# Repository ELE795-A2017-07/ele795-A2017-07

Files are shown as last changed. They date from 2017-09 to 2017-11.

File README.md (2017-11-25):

This is the project as handed out by the previous team. It used a Arduino node rather than a Raspberry Pi one.

# This is the BELIOT project
This is an Internet Of Things project.
This project contains an Arduino Nano which is the core microcontroller of module.
The module contains an RF circuit (inAir9B) with LoRaWAN technology. This node sends
data to a Raspberry Pi via RF and the Raspberry Pi posts its data to a Webserver via a Ruby script.
Webserver (Ruby on Rails app) can be reached at beliotv3.herokuapp.com. Data is stored into InfluxDB and can be visualized with Grafana.

This unit monitors:
- soil humidity and temperature
- air humidity and temperature
- Ozone concentration
- Dust concentration
- GPS
- Battery Life

Here is a picture of the Arduino node:
beliot_pic

Here is the circuitry inside the Stevenson Cage:
the_whole_thing

Here is the Raspberry Pi Gateway to receive/send data:
raspgithub

Here is a picture of a successful transmission from the Arduino node to the Raspberry Pi (seen on rasp console):
successfull_com

Here is the landing page of the website:


Here is some data plotted using Grafana:
some_data

The PCBs and electronics circuits were made using the KiCad software.

A User Manual (in French) is to be found on PDF.

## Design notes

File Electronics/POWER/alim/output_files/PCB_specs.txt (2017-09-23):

PCB specs
-2 layers external (Top, bottom)
-FR4 (130TG)
-Copper weight external: 1 oz/ft2 
-Core thickness:0.063"
-Legend color: white
-Mask color: green
-Finish: Lead-free HASL

https://www.eeweb.com/electronics-quiz/calculate-the-capacitance-of-pcb-planes
PCB cap: 1pF
-Solder mask min: 0.005"
-Traces et clearance min: 0.005"

http://circuitcalculator.com/wordpress/2006/01/31/pcb-trace-width-calculator/

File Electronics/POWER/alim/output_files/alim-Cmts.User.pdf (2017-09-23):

General specifications:
-2 layers external (Top, bottom) -Material: FR4
-Copper weight external: 1 oz/ft^2 -Silkscreen color: white
-Solder mask color: green
-Finish: Lead-free HASL
-Core thickness: 0.063"

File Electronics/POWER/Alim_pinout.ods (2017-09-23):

Signal | Broches | Description
Bat+ | 1 | Tension aux bornes de la batterie
uCV | 2 | Tension d’alimentation 5V fournie au microcontrôleur
5V | 3 | Tension d’alimentation 5V fournie aux senseurs
3.3V | 4 | Tension d’alimentation 3.3V fournie aux senseurs
3V | 5 | Tension d’alimentation 3V fournie aux senseurs
GND | 6 | Mise à la terre du circuit d’alimentation
EnuC ou EuC | 7 | Broche d’activation de l’alimentation du microcontrôleur. Haut niveau = actif, Bas niveau = inactif
EN5V ou E5V | 8 | Broche d’activation de l’alimentation des capteurs 5V. Haut niveau = actif, Bas niveau = inactif
EN3.3V ou E33V | 9 | Broche d’activation de l’alimentation des capteurs 3.3V. Haut niveau = actif, Bas niveau = inactif
EN3V ou E3V | 10 | Broche d’activation de l’alimentation des capteurs 3V. Haut niveau = actif, Bas niveau = inactif
SolCtrl | 11 | Permet d’asservir le chargeur avec des niveaux logiques, si les connecteurs sont connecté en mode nMOS. Bas niveau = panneau solaire connecté au chargeur. Haut niveau = panneau solaire déconnecté du chargeur
Status | 12 | Donne le status de charge de la batterie. Niveau haut = charge complétée. Bas niveau = batterie en chargement. Haute impédance = hors service ou pas de batterie.

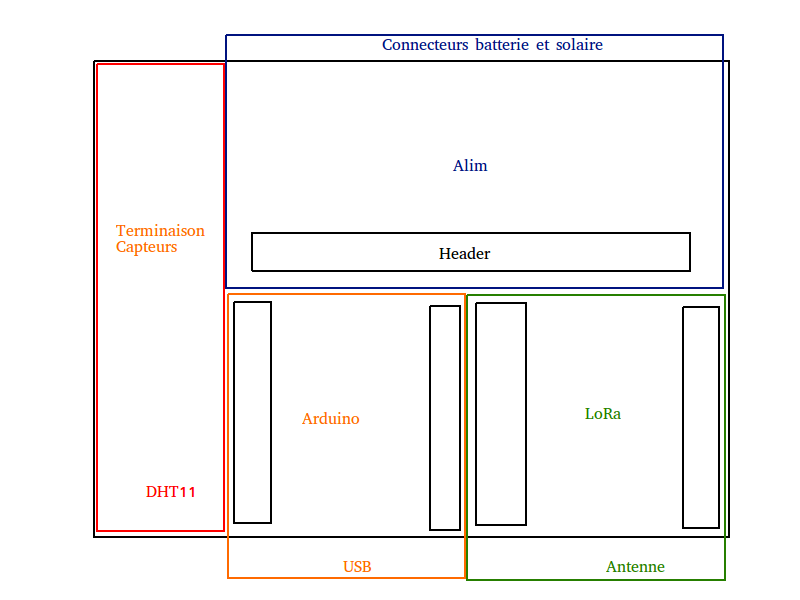
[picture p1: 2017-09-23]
Electronics/SENSOR_UNIT/Disposition_physique.png

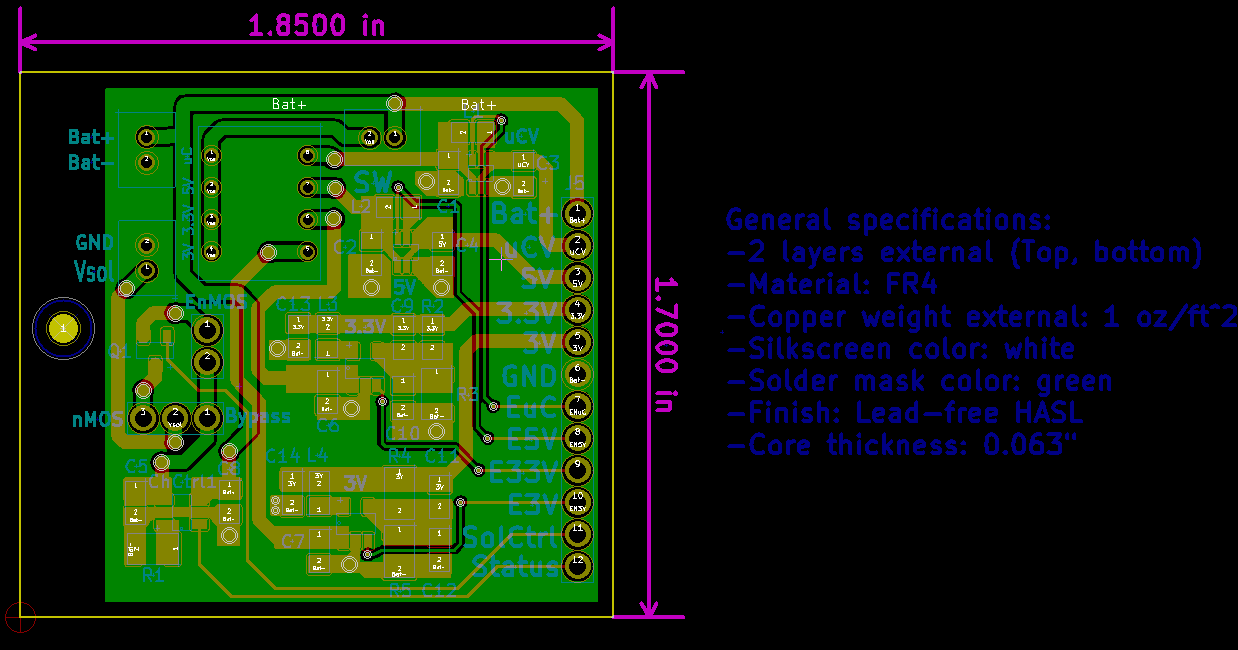
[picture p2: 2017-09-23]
Electronics/POWER/TopNBottom.png

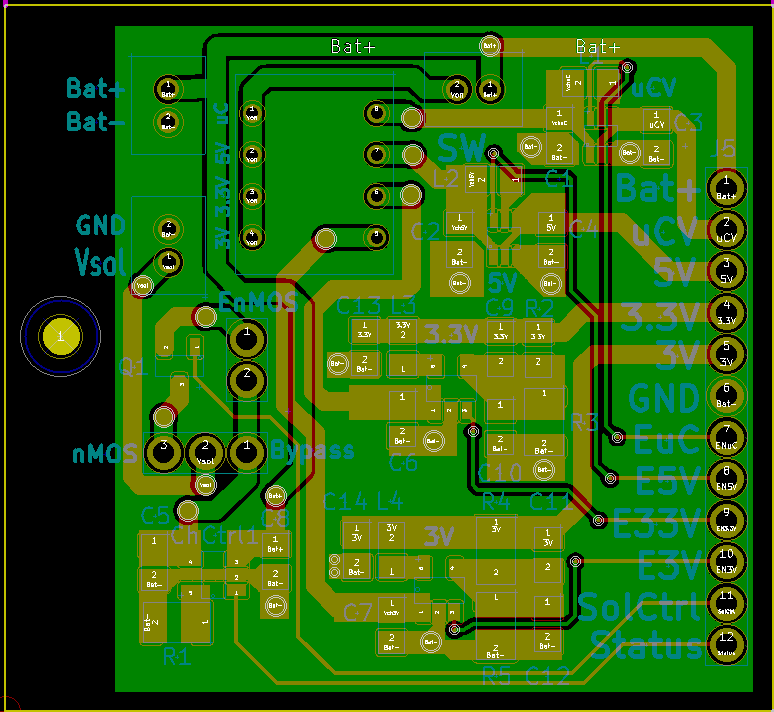
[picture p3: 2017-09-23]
Electronics/POWER/alim/pcb_power.png

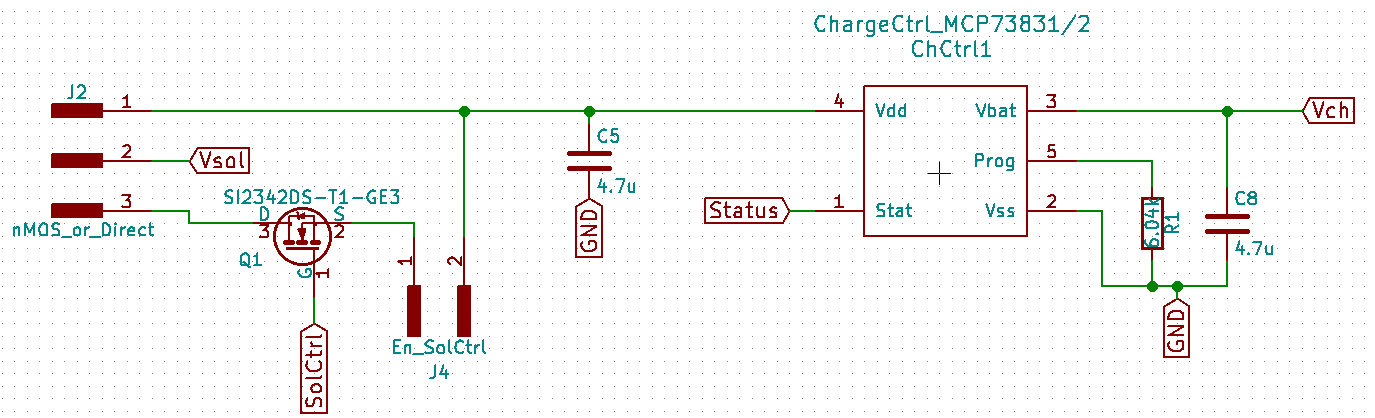
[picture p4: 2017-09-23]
Electronics/POWER/reg_chargeur.png

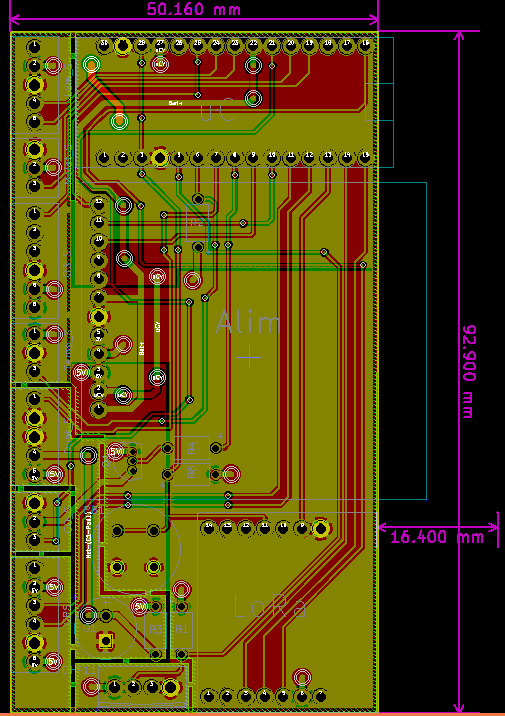
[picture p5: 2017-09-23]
Electronics/SENSOR_UNIT/PCB_final_taille.png

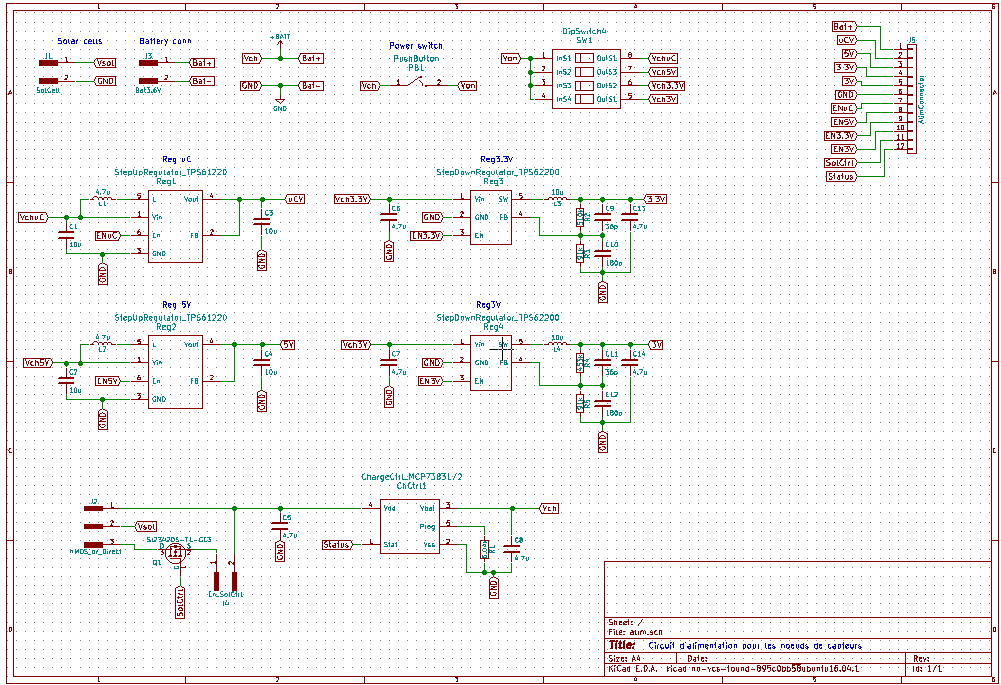
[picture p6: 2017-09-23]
Electronics/POWER/Circuit_power.png

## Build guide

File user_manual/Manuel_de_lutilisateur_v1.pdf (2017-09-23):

# Manuel de l’utilisateur v1

Noeud + Passerelle LoRa, Projet Beliot

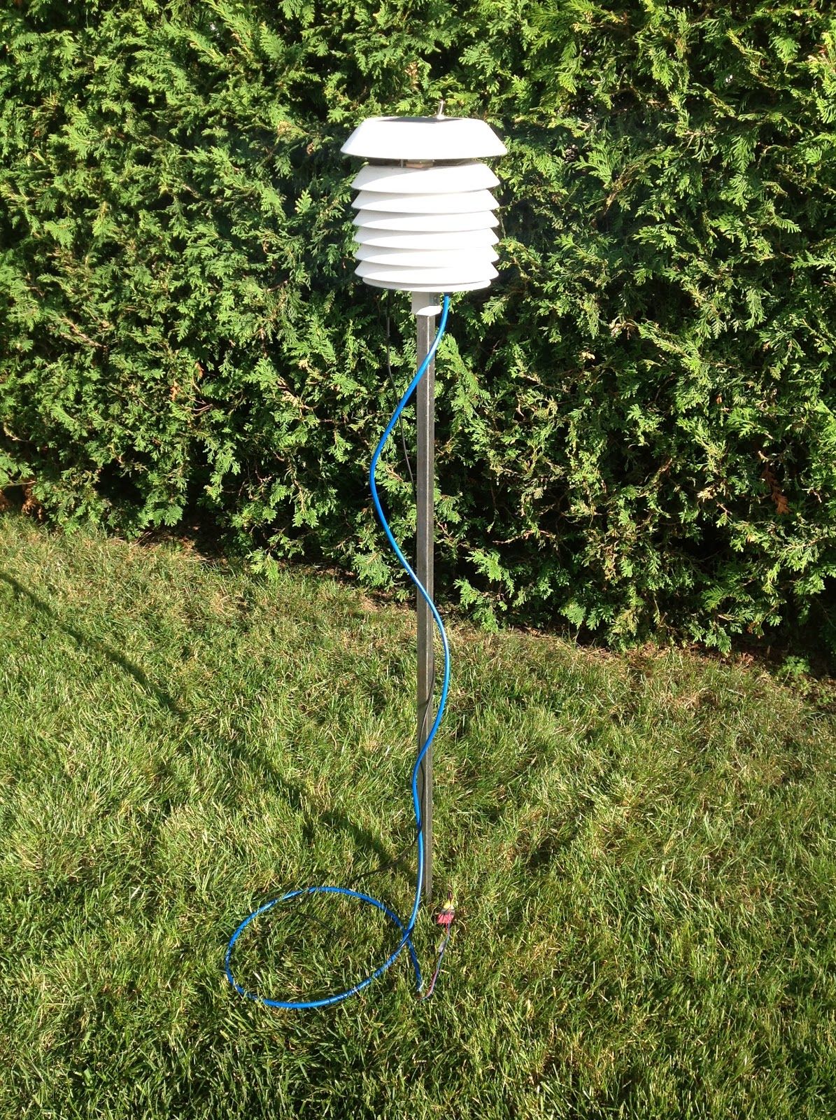
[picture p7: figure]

Par
Vincent Gosselin

Fait le 8 Août 2017

# Table des matières

Installation de la passerelle | p.3-5
Installation du noeud | p.5-6
La Plateforme Web | p.7
Où trouver le travail réalisé | p.7
Considérations importantes | p.8

# Installation de la passerelle

1. Brancher le Raspberry Pi dans un routeur à l’aide d’un cable Ethernet.
2. Brancher l’alimentation du Raspberry Pi.
3. Mettre le Raspberry PI a “ON’’ (alimenter)
4. Découvrir et noter le IP local du Raspberry PI à l’aide de la page web du routeur. Chez moi, le routeur à l’adresse ‘’http//home/”.
5. À l’aide de la console tapez :
‘’ssh pi@XXX.XXX.XXX.XXX’’
où XXX.XXX.XXX.XXX correspond au IP découvert à l’étape 4.
6. Le mot de passe est :
‘’raspberry’’
7. Une fois entrer dans le raspberry pi, tapez la commande : ‘’tmux ls’’.
La commande va retourner un message d’erreur si il n’y a pas de session tmux déjà lancé:

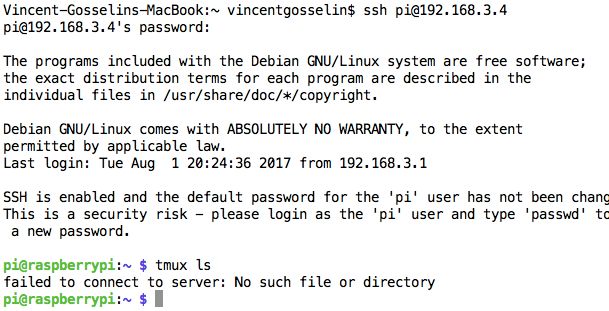
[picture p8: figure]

Si il y avait un serveur tmux de disponible, il suffit de tapper “tmux attach’’ pour se connecter à la session tmux.

8. Tapez la commande ‘’tmux’’ pour démarrer une nouvelle session tmux.
Une fois la session tmux lancé, une barre verte apparait en bas d’écran.

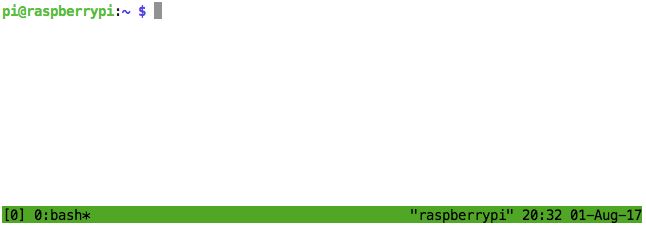
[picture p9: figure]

9. Entrer la commande ‘’cd /home/pi/Desktop/LowCostLoRaGw/lora_gateway’’ pour accéder au répertoire de la passerelle LoRa.

10. Taper ‘’ls’’ pour voir le contenu du dossier.
À titre d’information :
- Le script STARTGATEWAY.sh sert à activer la passerelle.
- Le fichier lora_gateway.cpp sert à la configuration de la bande de fréquence du module LoRa. En Amérique, il s’agit de la bande 915 MHz. En Europe, il s’agit de la bande de 868 MHz. Après chaque modification de lora_gateway.cpp, il faut recompiler avec la commande ‘’make lora_gateway_pi2’’. Le raspberry pi a déjà été configuré en 868MHz.
- Le fichier post_to_influxdb_v3.rb sert à envoyer les données reçues de la passerelle vers la plateforme Web. Ce fichier a été placé dans clouds.json pour être appellé via le script post_processing_gw.py

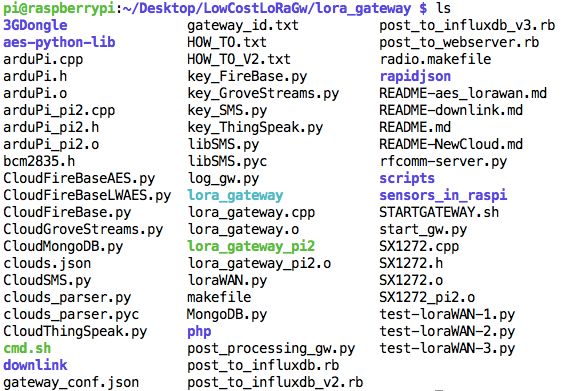
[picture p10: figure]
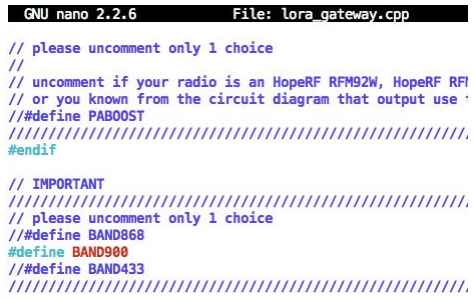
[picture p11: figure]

11. Taper ‘’bash STARTGATEWAY.sh’’ pour activer la passerelle. L’écran devrait alors avoir l’allure suivante :

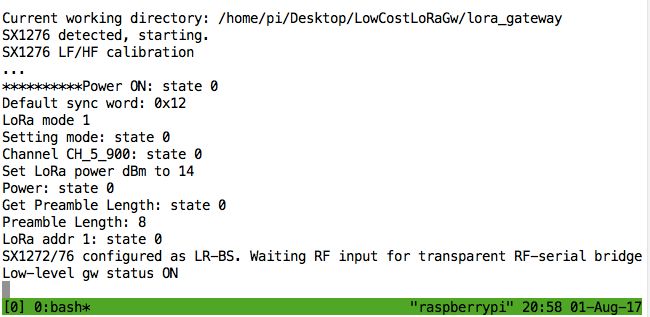
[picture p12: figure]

12. Enfoncer (CTRL+B), Relacher et appuyer sur D pour se déttacher de la session tmux.

13. Taper ‘’exit’’ pour se déconnecter du raspberry pi.

La passerelle est maintenant configuré.

# Installation de noeud

1. Planter la barre dans le sol a l’aide d’un maillet.
2. Installer la tête du prototype sur la barre de fer et visser la tête sur la barre de fer.

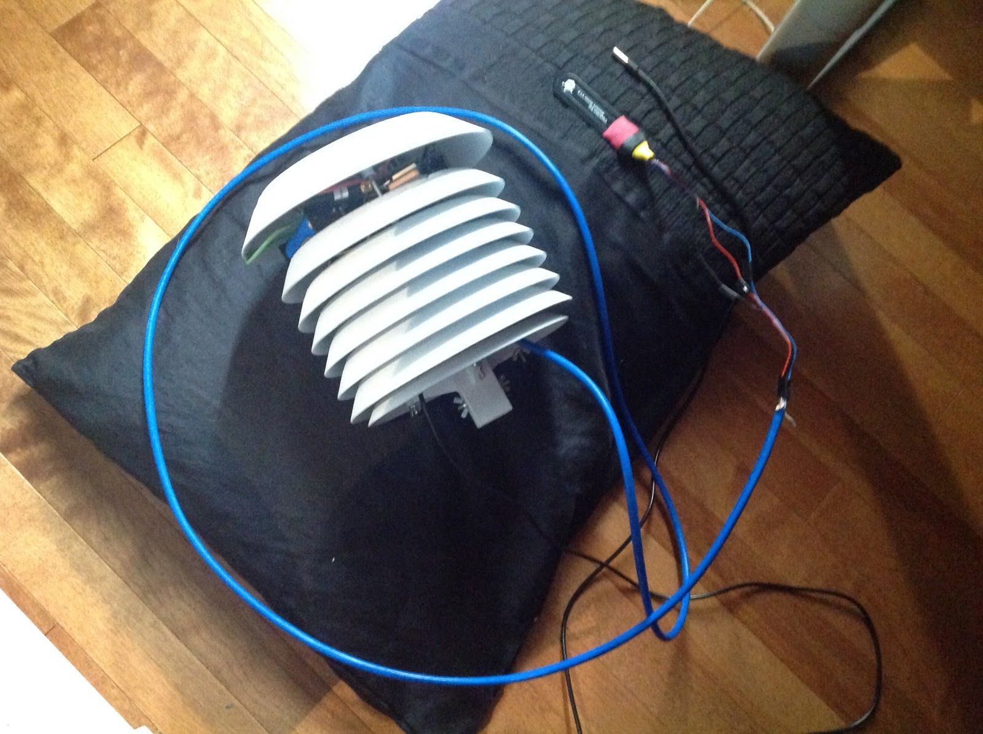
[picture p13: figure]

3. Activer la SWITCH à ON sur la tête du prototype pour mettre le noeud en mode actif.

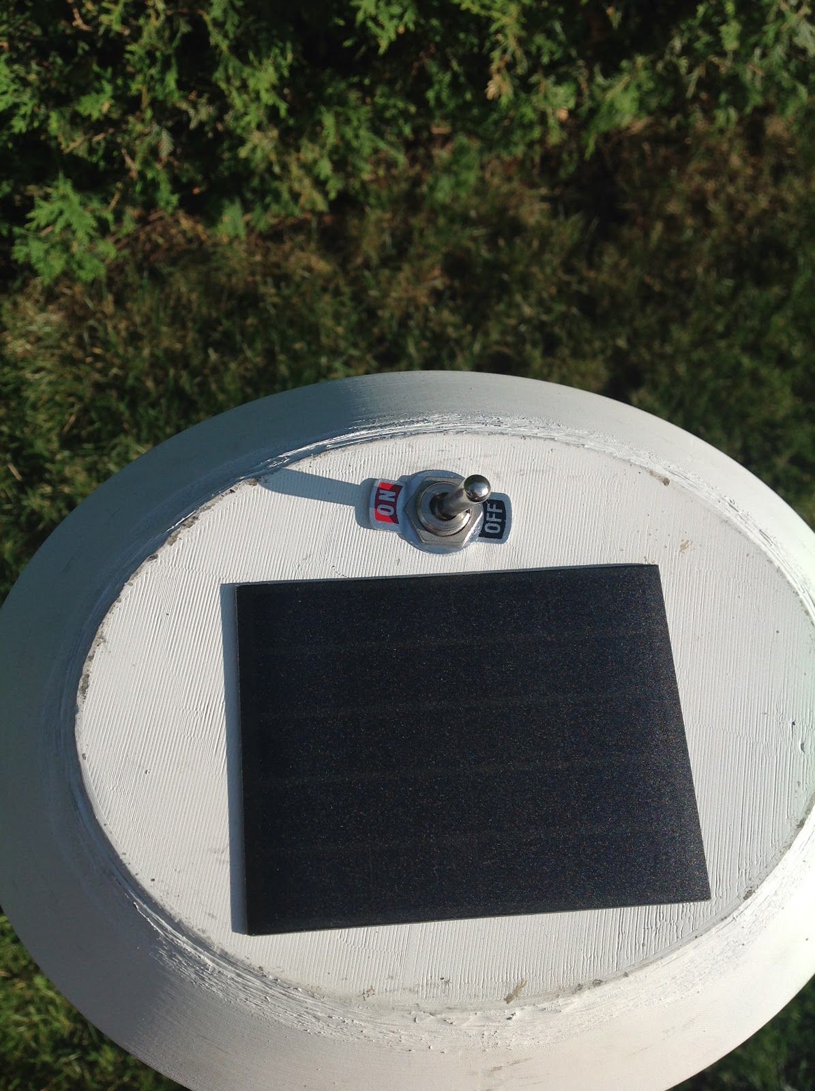
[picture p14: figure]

4. Après 40 secondes, un message sera reçu sur le rasp dans la session tmux pour indiquer une communication réussi.

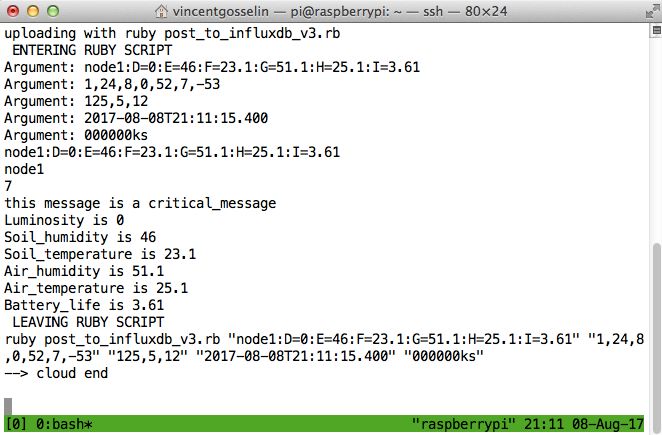
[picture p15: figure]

6. Planter dans le sol la sonde de température et la sonde d’humiditié.
7. En cas, d’échec de cette réception de donnée, Switch -> OFF, Switch -> ON, devrait réussir la communication. Parfois (rarement), il y a une erreur LoRa pendant la première transmission. Donc, éteindre et ré-allumer le prototype devrait faire.
8. Noter qu’il serait important d’avoir un recouvrement de la tête sur la partie supérieure afin de protéger la partie électronique du contact de l’eau.
9. Pour programmer le arduino attaché au prototype, il est très important de mettre la SWITCH à OFF avant de connecter le port USB.

# La plateforme Web

1. La plateforme Web est accessible à l’adresse beliotv3.herokuapp.com
2. Pour avoir les prévisions locales, Cliquer sur l’image de la météo.
3. Pour l’historique du noeud, Cliquer sur l’image de Grafana.
4. Sur Grafana, Usager : ‘’client’’ Mot de passe : ‘’vignesbordeaux’’
5. Sélectionner le Dashboard ‘’vignes_bordeaux_v1’’

Pour l’info, le site web est contenu sur la plateforme Heroku et est codé en Ruby. Le code du site web est disponible sur Github : https://github.com/vincentgosselin1/beliotv3 . La base de données Influxdb + Grafana sont hébergé sur la plateforme de Amazon Web Services.

Notez que la gratuité de la plateforme Web sur Amazon Web Services prend fin Mai 2018, prière de communiqué vincentgosselin1@gmail.com avant la date d’échéance.

# Où trouver le travail réalisé

1. La totalité du travail se trouve à l’adresse : https://github.com/vincentgosselin1/Arduino_node
2. Le code principale qui doit être flashé dans le arduino nano se trouvre dans le dossier Main et se nomme ‘’main.cpp”. Afin de compiler le code dans le arduino, il est important de copier/coller la totalité du fichier main.cpp dans un fichier .ino pour flasher le arduino. En plus, il faut copier le contenu du dossier ‘’libraries’’ dans le répertoire des libraries Arduino. Sur mon Macbook, la location de ce dossier se trouve dans ‘’/Users/vincentgosselin/Documents/Arduino/libraries’’.
3. Les projets Kicad pour les circuits électriques ainsi que les pcbs sont inclus dans le Github dans la section Electronics.

# Considération importantes

1. Le module consomme plus que prévue, un erreur au niveau de la conception électrique sur un régulateur force la consommation à 150mA en mode actif et à 60mA en mode économie d’énergie. La faute est à cause de la ligne 5V qui ne va pas à 0V quand le régulateur ‘’shut-off’’. En enlevant le GPS + Détecteur de poussière, la consommation passe à 40mA en mode actif et 10mA en mode économie d’énergie. Pour une raison qu’on ignore encore, le mode économie d’énergie observer sur plaque d’essais, ne descend pas jusqu’à 0.25mA. Ceci est à investiguer.
2. Il faut recouvrir la partie suppérieure de la tête du prototype pour le rendre imperméable à l’eau (la partie inférieur l’est). Du simple “Duck tape’’ fait l’affaire.
3. Un optimisation de code a été fait mais elle s’est avéré inéfficace puisque le programme atteignait 98% de mémoire statique et 80% mémoire dynamique avec l’inclusion du capteur de luminosité. La communication LoRa ne fonctionnait pas et un message de ‘’warning’’ sur Arduino apparaissait. Alors, c’est pour cette raison que le capteur de luminosité ne fait pas partie du prototype. Le code est stable maintenant.

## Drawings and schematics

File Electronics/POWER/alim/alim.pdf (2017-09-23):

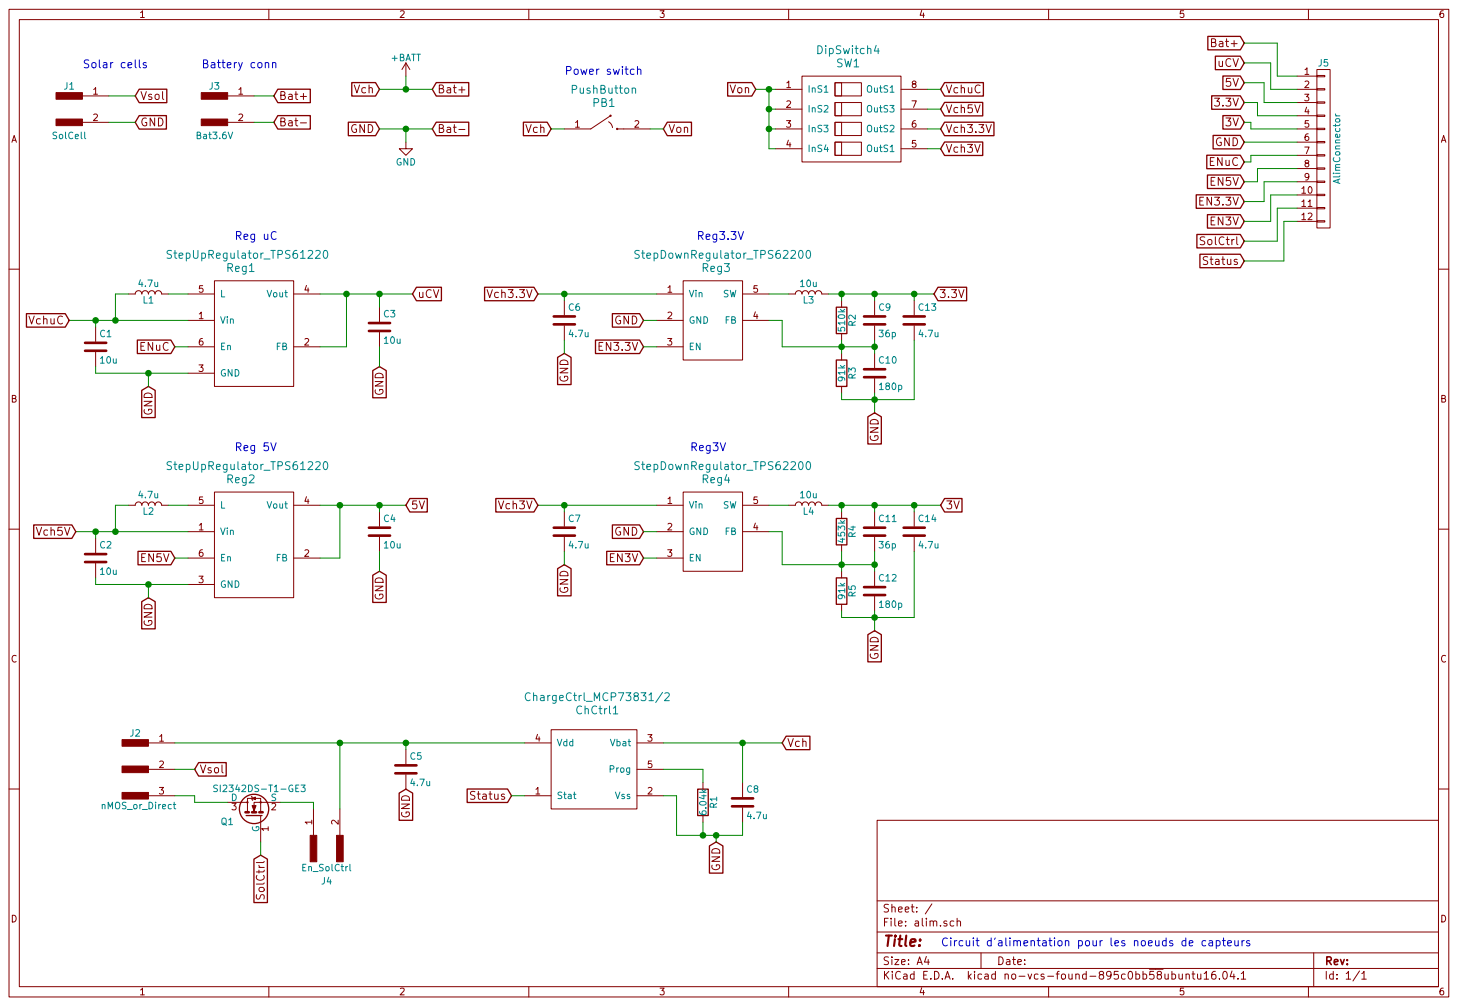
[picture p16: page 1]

Circuit d'alimentation pour les noeuds de capteurs

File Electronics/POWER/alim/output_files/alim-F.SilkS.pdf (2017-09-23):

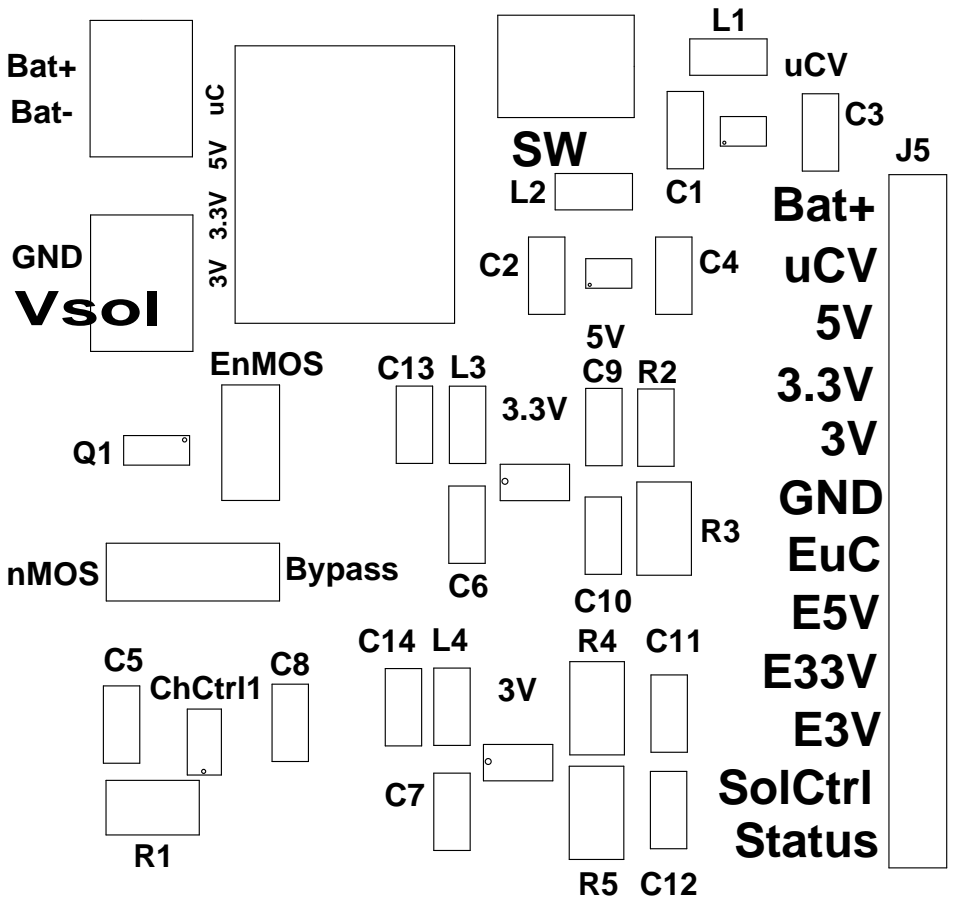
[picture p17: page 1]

3V 3.3V 5V uC EnMOS Bat- nMOS Bypass Bat+ Vsol SW

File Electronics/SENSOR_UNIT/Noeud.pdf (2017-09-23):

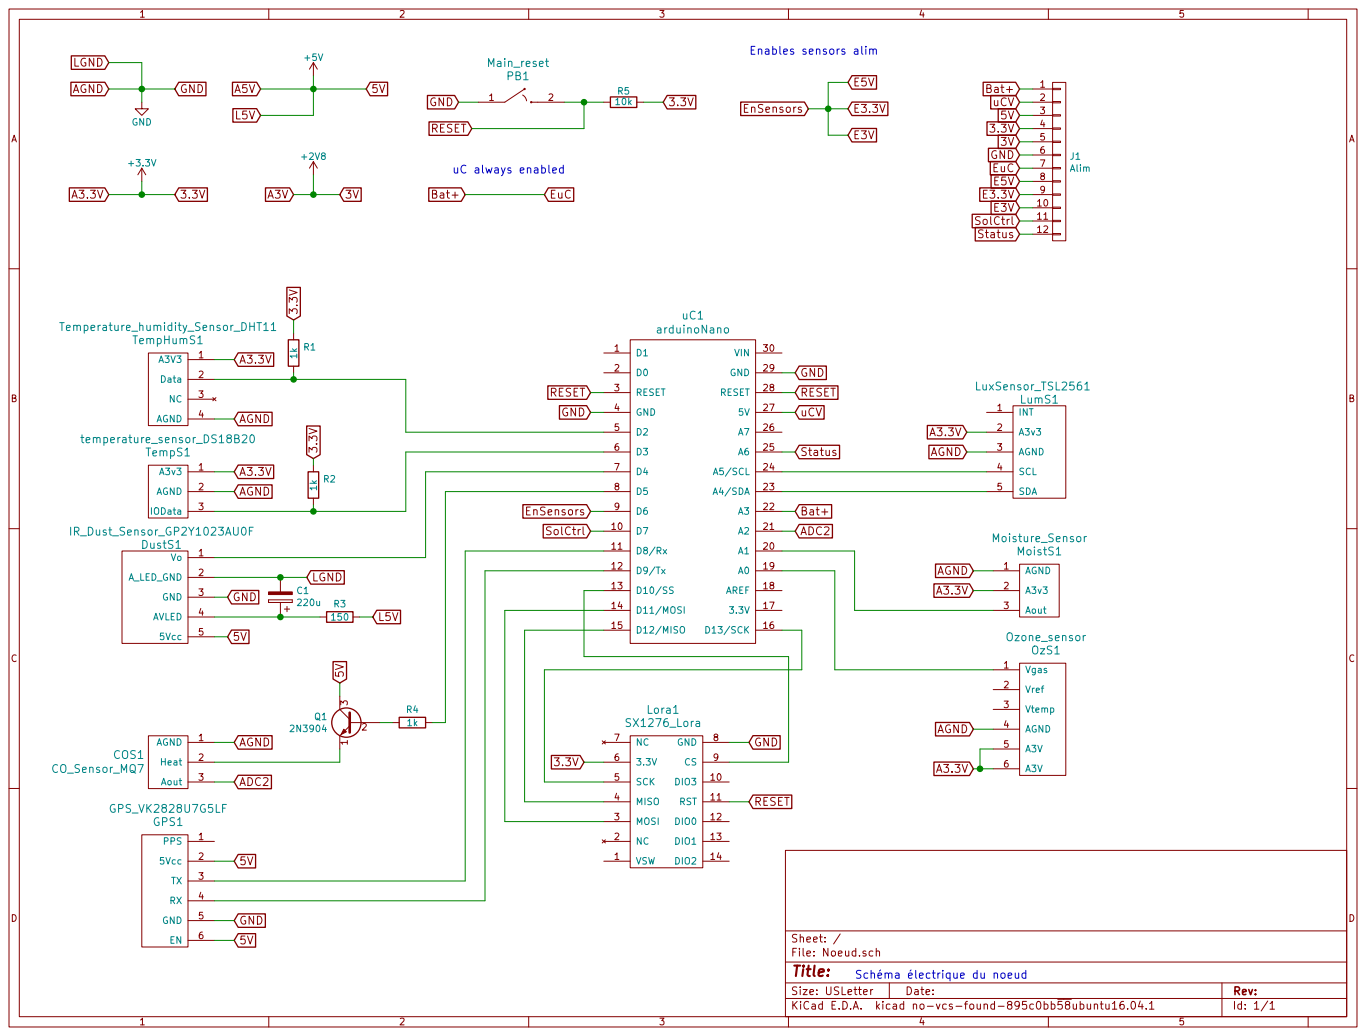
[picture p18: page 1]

Id: 1/1 Title: File: Noeud.sch Sheet: /

Schéma électrique du noeud

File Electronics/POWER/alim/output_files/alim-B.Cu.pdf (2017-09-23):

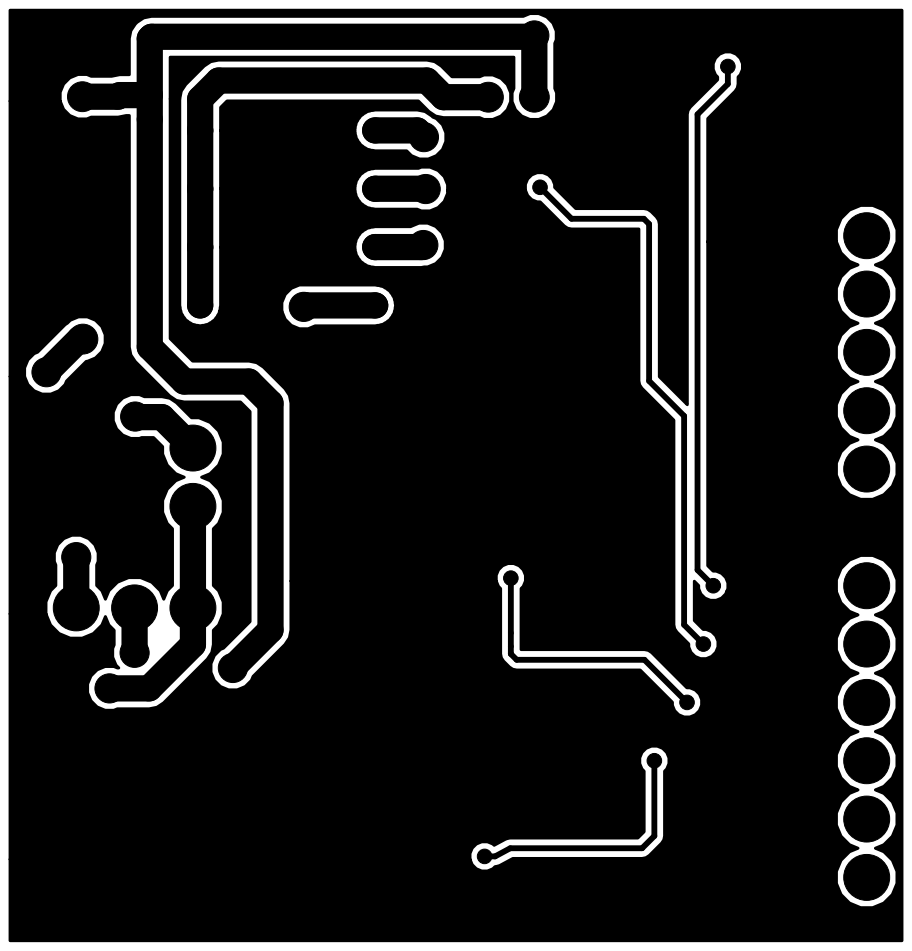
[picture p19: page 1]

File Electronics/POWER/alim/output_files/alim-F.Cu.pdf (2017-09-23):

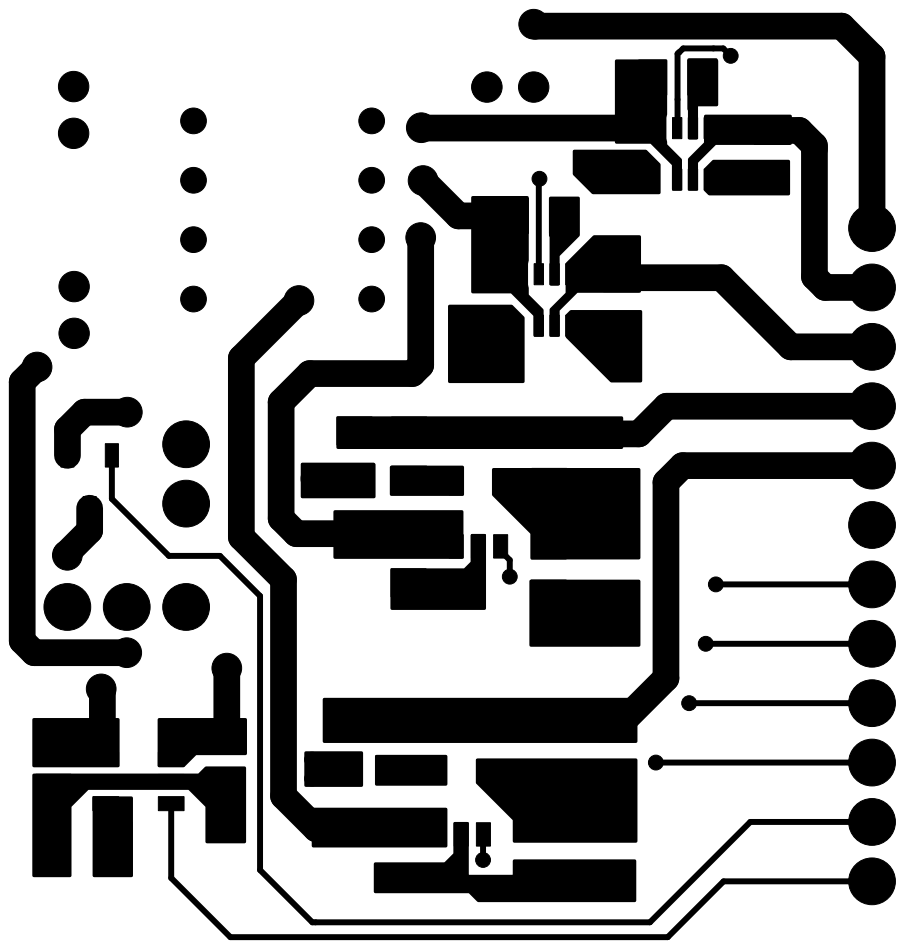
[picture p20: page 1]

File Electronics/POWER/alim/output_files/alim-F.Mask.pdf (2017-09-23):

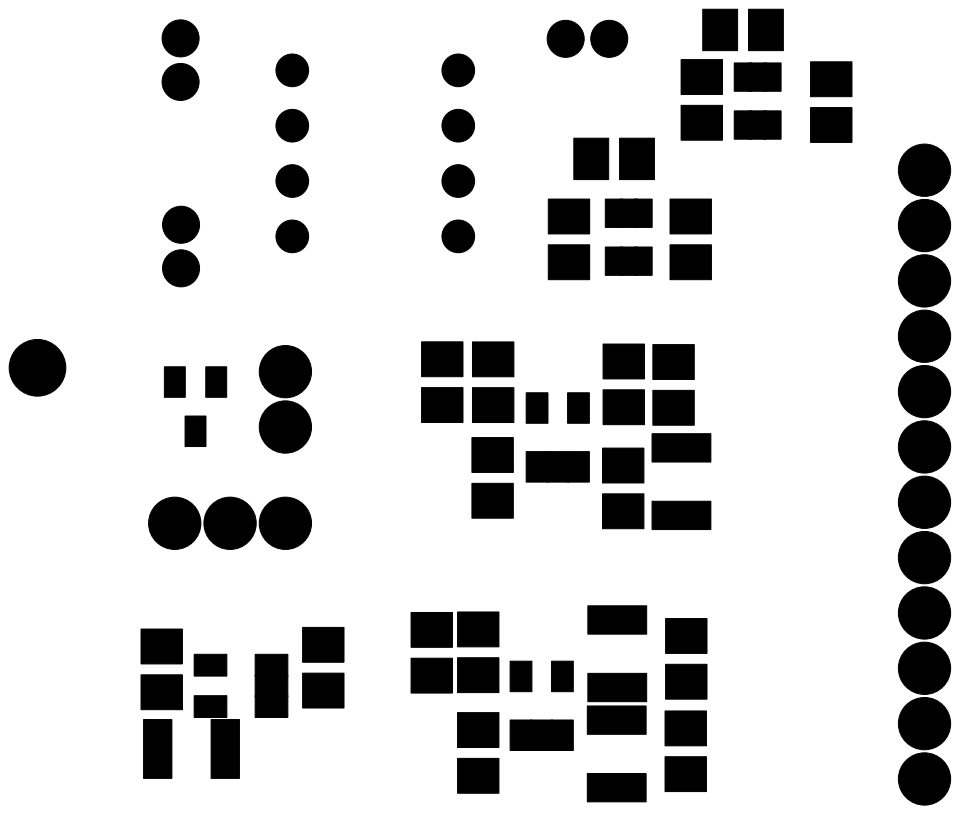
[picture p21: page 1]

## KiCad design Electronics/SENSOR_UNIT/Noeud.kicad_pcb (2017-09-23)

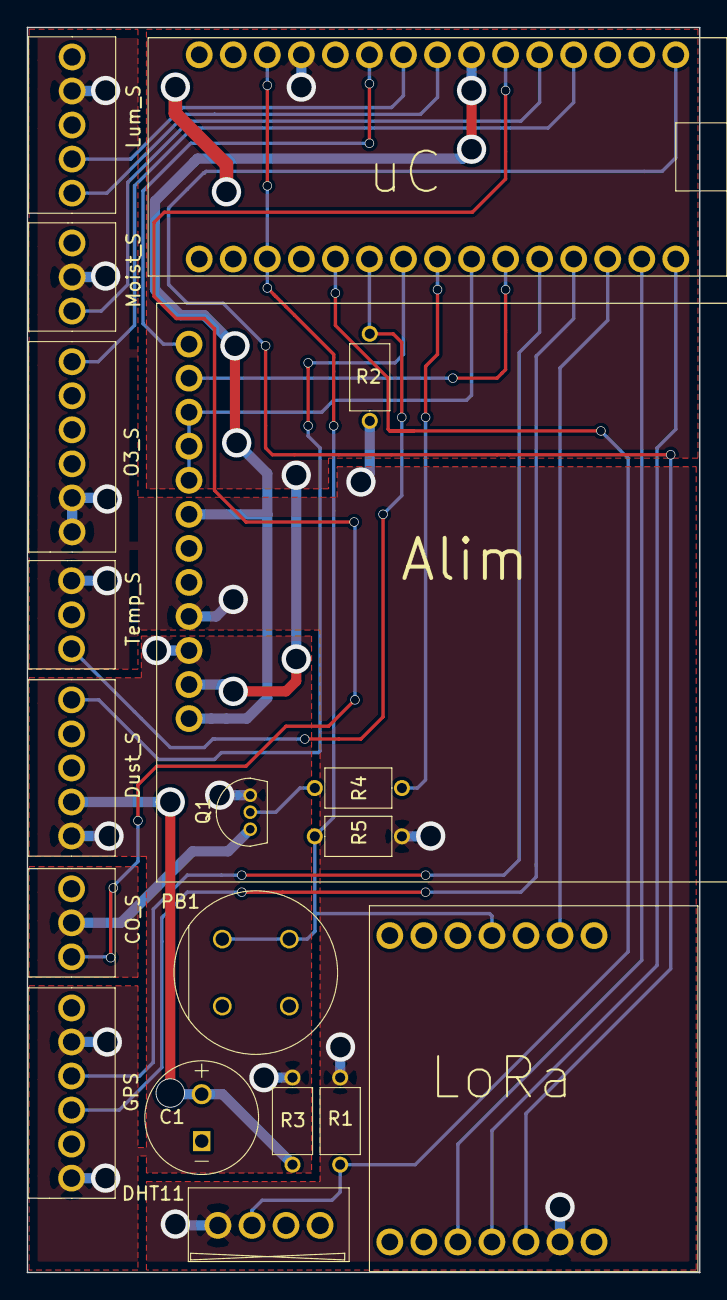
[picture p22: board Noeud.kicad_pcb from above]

Board: 2 copper layers, 50.2 x 92.9 mm, 19 parts (0 on the bottom side), 27 nets.

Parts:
C1: 220u; Axial_cap_220u
CO_S: CO_Sensor_MQ7; Block_terminal_X3
DHT11: Temperature_humidity_Sensor_DHT11; DHT11
Dust_S: IR_Dust_Sensor_GP2Y1023AU0F; Block_terminal_X5
GPS: GPS_VK2828U7G5LF; Block_terminal_X6
J1: Alim; Header_X12_0p1_power
LoRa: SX1276_Lora; SX1276_LoRa
Lum_S: LuxSensor_TSL2561; Block_terminal_X5
Moist_S: Moisture_Sensor; Block_terminal_X3
O3_S: Ozone_sensor; Block_terminal_X6
PB1: Main_reset; PushButton
Q1: 2N3904; Transistor_TO-92
R1, R2, R4: 1k; Axial_resistor_0p25W
R3: 150; Axial_resistor_0p25W
R5: 10k; Axial_resistor_0p25W
Temp_S: temperature_sensor_DS18B20; Block_terminal_X3
uC: arduinoNano; ArduinoNano

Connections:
3.3V: DHT11.1, J1.4, LoRa.6, Lum_S.2, Moist_S.2, O3_S.5, O3_S.6, R1.1, R2.1, R5.2, Temp_S.1
5V: Dust_S.5, GPS.2, GPS.6, J1.3, Q1.3, R3.1
ADC2: CO_S.3, uC.21
AGND: C1.2, CO_S.1, DHT11.4, Dust_S.2, Dust_S.3, GPS.5, J1.6, LoRa.8, Lum_S.3, Moist_S.1, O3_S.4, PB1.1, Temp_S.2, uC.4, uC.29
Bat+: J1.1, J1.7, uC.22
E3.3V: J1.8, J1.9, J1.10, uC.9
unnamed: C1.1, Dust_S.4, R3.2
unnamed: CO_S.2, Q1.1
unnamed: Dust_S.1, uC.7
unnamed: GPS.3, uC.11
unnamed: GPS.4, uC.12
unnamed: LoRa.3, uC.14
unnamed: LoRa.4, uC.15
unnamed: LoRa.5, uC.16
unnamed: LoRa.9, uC.13
unnamed: Lum_S.4, uC.24
unnamed: Lum_S.5, uC.23
unnamed: Moist_S.3, uC.20
unnamed: O3_S.1, uC.19
unnamed: Q1.2, R4.2
unnamed: DHT11.2, R1.2, uC.5
unnamed: R2.2, Temp_S.3, uC.6
unnamed: R4.1, uC.8
RESET: LoRa.11, PB1.2, R5.1, uC.3, uC.28
SolCtrl: J1.11, uC.10
Status: J1.12, uC.25
uCV: J1.2, uC.27

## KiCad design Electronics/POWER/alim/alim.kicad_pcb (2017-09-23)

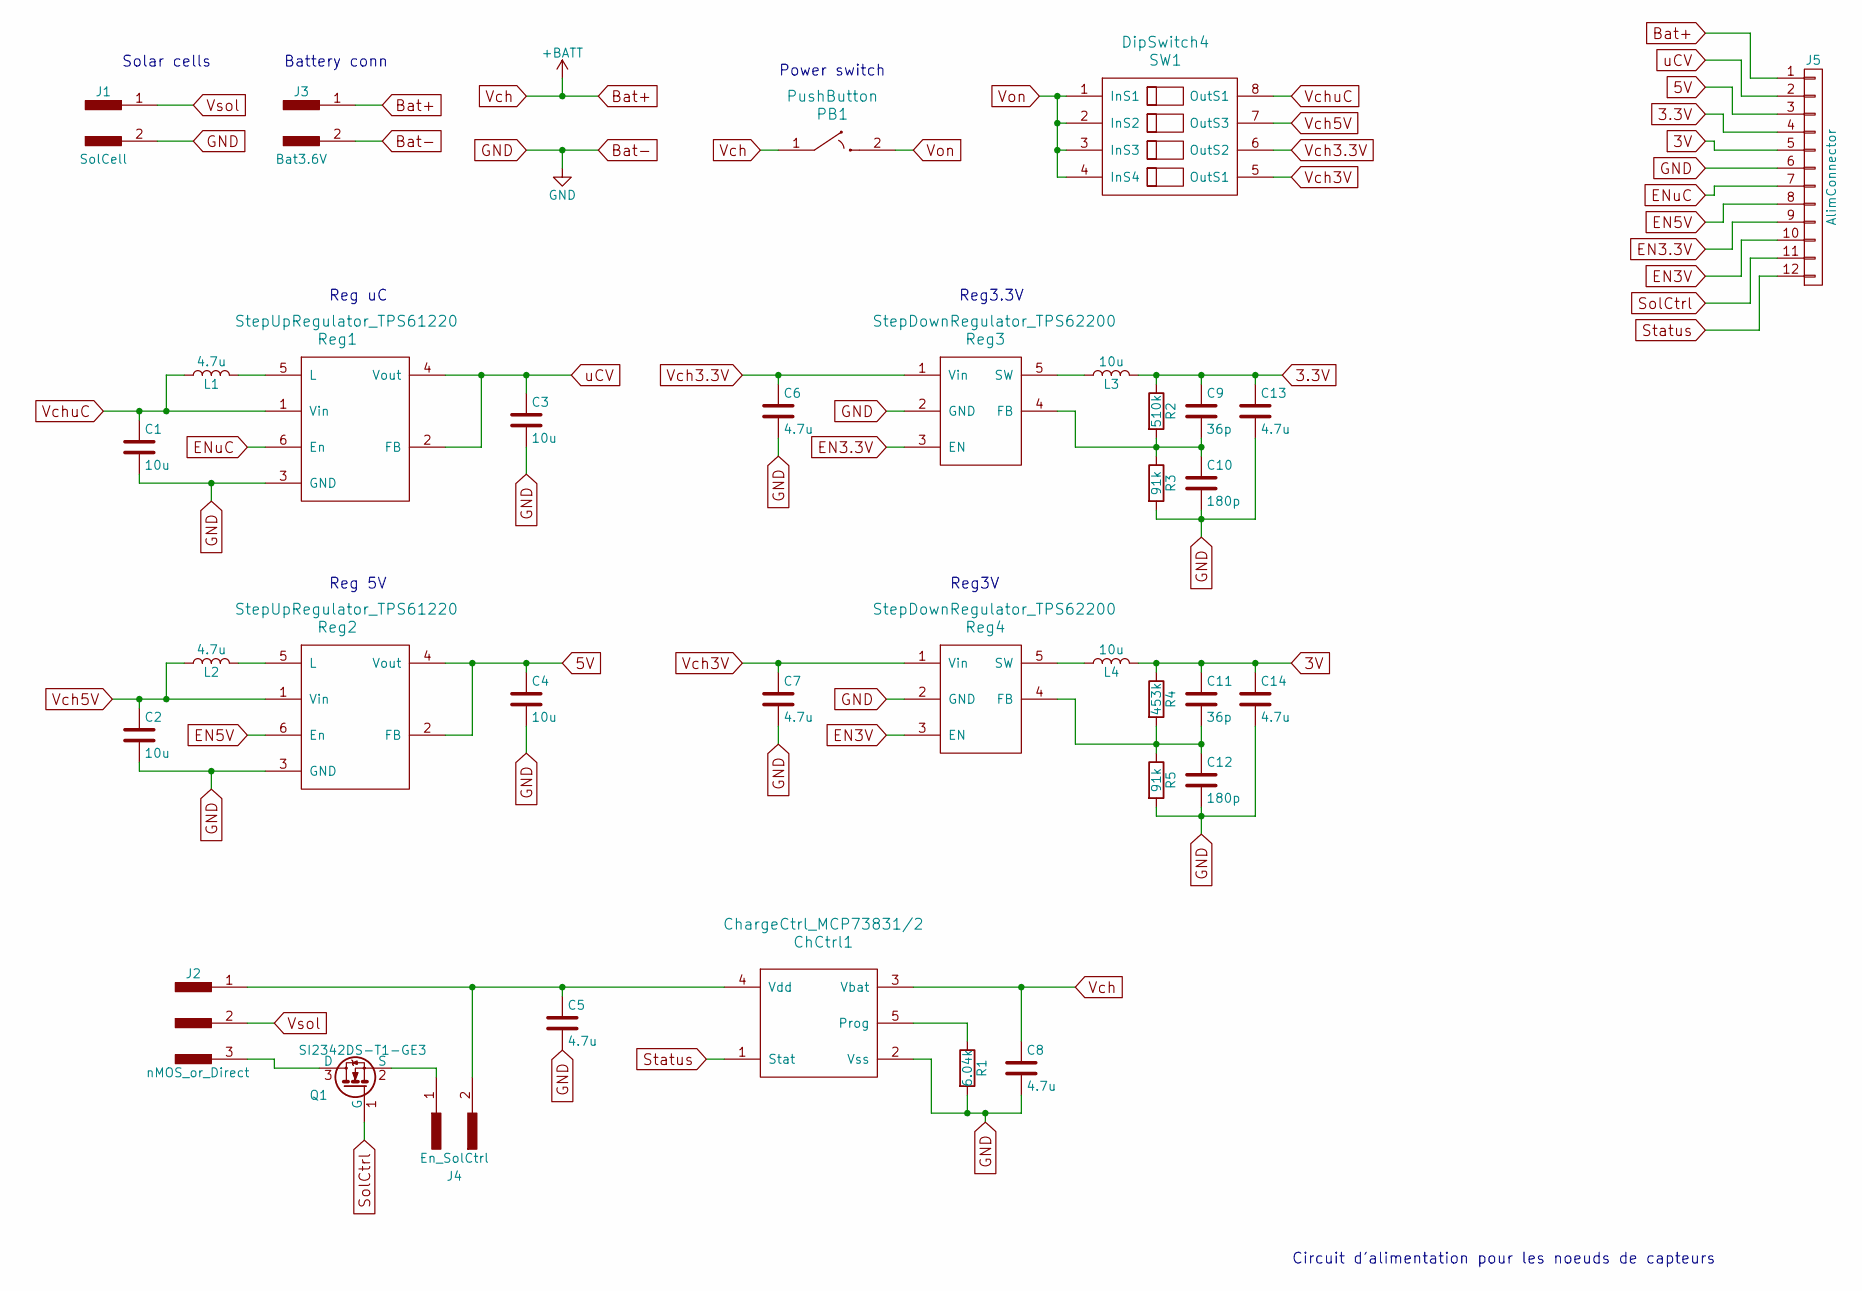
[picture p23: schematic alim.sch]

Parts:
C1, C3: 10u; 0805; Voltage 6.3; Tolerance 10%
C2, C4: 10u; 0805
C5, C6, C7, C8, C13, C14: 4.7u; 0805
C9, C11: 36p; 0805
C10, C12: 180p; 0805
ChCtrl1: ChargeCtrl_MCP73831/2; SOT-23-5_MCP7383X
J1: SolCell; Connect_X2_Power
J2: nMOS_or_Direct; Header_X3_0p1
J3: Bat3.6V; Connect_X2_Power
J4: En_SolCtrl; Header_X2_0p1
J5: AlimConnector; Header_X12_0p1
L1: 4.7u; 0805; Tolerance 10%
L2: 4.7u; 0805
L3, L4: 10u; 0805
PB1: PushButton; Connect_X2_Power
Q1: SI2342DS-T1-GE3; SOT-23_SI2342DS
R1: 6.04k; 1210
R2: 510k; 0805
R3, R5: 91k; 1210
R4: 453k; 1210
Reg1, Reg2: StepUpRegulator_TPS61220; SOT-363_TPS61222
Reg3, Reg4: StepDownRegulator_TPS62200; SOT-23-5_TPS6220x
SW1: DipSwitch4; DIP_Switch_X4

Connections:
3.3V: C9.1, C13.1, J5.4, L3.2, R2.1
3V: C11.1, C14.1, J5.5, L4.2, R4.1
5V: C4.1, J5.3, Reg2.2 (FB), Reg2.4 (Vout)
Bat+: C8.1, ChCtrl1.3 (Vbat), J3.1, J5.1, PB1.1
Bat-: C1.2, C2.2, C3.2, C4.2, C5.2, C6.2, C7.2, C8.2, C10.2, C12.2, C13.2, C14.2, ChCtrl1.2 (Vss), J1.2, J3.2, J5.6, R1.2, R3.2, R5.2, Reg1.3 (GND), Reg2.3 (GND), Reg3.2 (GND), Reg4.2 (GND)
EN3.3V: J5.9, Reg3.3 (EN)
EN3V: J5.10, Reg4.3 (EN)
EN5V: J5.8, Reg2.6 (En)
ENuC: J5.7, Reg1.6 (En)
unnamed: C5.1, ChCtrl1.4 (Vdd), J2.1, J4.2
unnamed: C9.2, C10.1, R2.2, R3.1, Reg3.4 (FB)
unnamed: C11.2, C12.1, R4.2, R5.1, Reg4.4 (FB)
unnamed: ChCtrl1.5 (Prog), R1.1
unnamed: J2.3, Q1.3 (D)
unnamed: J4.1, Q1.2 (S)
unnamed: L1.1, Reg1.5 (L)
unnamed: L2.1, Reg2.5 (L)
unnamed: L3.1, Reg3.5 (SW)
unnamed: L4.1, Reg4.5 (SW)
SolCtrl: J5.11, Q1.1 (G)
Status: ChCtrl1.1 (Stat), J5.12
Vch3.3V: C6.1, Reg3.1 (Vin), SW1.6 (OutS2)
Vch3V: C7.1, Reg4.1 (Vin), SW1.5 (OutS1)
Vch5V: C2.1, L2.2, Reg2.1 (Vin), SW1.7 (OutS3)
VchuC: C1.1, L1.2, Reg1.1 (Vin), SW1.8 (OutS1)
Von: PB1.2, SW1.1 (InS1), SW1.2 (InS2), SW1.3 (InS3), SW1.4 (InS4)
Vsol: J1.1, J2.2
uCV: C3.1, J5.2, Reg1.2 (FB), Reg1.4 (Vout)

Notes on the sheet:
Solar cells
Battery conn
Reg 5V
Reg uC
Reg3V
Reg3.3V
Circuit d'alimentation pour les noeuds de capteurs
Power switch

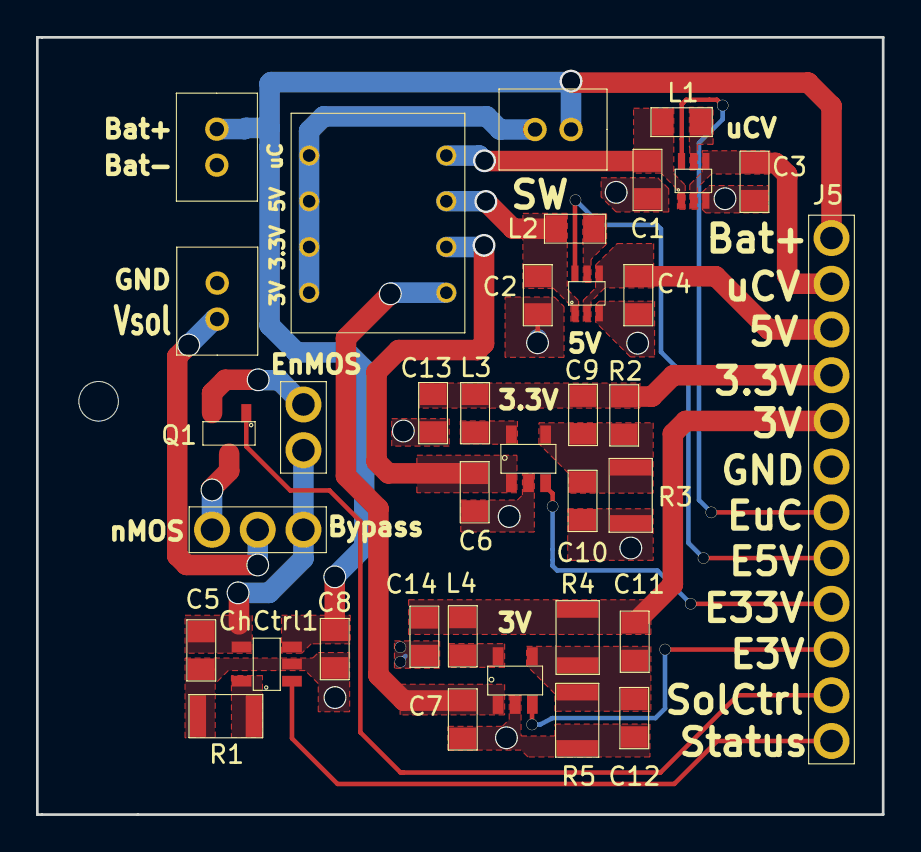
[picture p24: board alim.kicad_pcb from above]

Board: 2 copper layers, 47.0 x 43.2 mm, 36 parts (0 on the bottom side), 28 nets.

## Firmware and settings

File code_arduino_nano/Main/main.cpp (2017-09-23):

/*	
By Vincent Gosselin, 2017.

The following is a program to monitor
all the sensors execpt CO, LUX sensor in Vincent's Room.

The state machine of the program :
1 : Deep sleep (0.27mA) for 1h and 10minutes
2 : if 10 minutes done, SCAN soil/air sensors + battery,
3 : if 1h done, SCAN O3/Dust/GPS
4 : Construct a string to send to InfluxDB (inside a AWS server)
5 : Send the string using the Lora Module
*/

//This is using a nice library to simplify the code.
#include "Lora_simplified.h"
//Custom tools for a better code.
#include "arduinotools.h"

//Library for lowpower
//#include "LowPower.h"
#include <avr/sleep.h>
#include <avr/wdt.h>
#include <avr/power.h>
#include <avr/interrupt.h>

//All the custom libraries
//#include "arduinonanodht11.h"
#include "arduinonanodht22.h" // <- DHT22 definately better!
#include "sharp_dust_sensor.h"
#include "GPS_v2_library.h"// Successfully reduced Dynamic memory usage from 26% to 19% in this version.
//#include "GPS_Library.h" <- definitly cannot use, breaks the whole thing...
//#include "Lux_Sensor.h" 
//#include "Lux_sensor_library_v2" <- actually worse in memory usage
//#include "MQ7_Sensor.h"
#include "O3_spec_sensor.h"
#include "arduino_soil_moisture.h"
#include <arduino_nano_DFR0198.h>

//For Deep sleep
//#define ONE_HOUR_TIMEOUT 3350
//#define TEN_MINUTES_TIMEOUT 490
//#define TWO_MINUTES_TIMEOUT 98
//#define TWO_MINUTES_TIMEOUT 300
#define ONE_MINUTE_TIMEOUT 60
#define TWO_MINUTES_TIMEOUT 120 // 
#define FIVE_MINUTES_TIMEOUT 300 // IN SECONDES
#define TEN_MINUTES_TIMEOUT 600 
#define ONE_HOUR_TIMEOUT 3600
//watchdog_counter = 49 for 0.85min.
//watchdog_counter = 98 for 1.7min on Grafana
//watchdog_counter = 490 for 8.43min on Grafana.
//watchdog_counter = 3350 for 58min? Actually equals to 57min30sec. Close Enough!
//volatile unsigned int watchdog_counter = 3350;
volatile unsigned int long_watchdog_counter = ONE_HOUR_TIMEOUT;
//volatile unsigned int short_watchdog_counter = 0;
//volatile unsigned int long_watchdog_counter = 0;
volatile unsigned int short_watchdog_counter = TEN_MINUTES_TIMEOUT;

ISR(WDT_vect) {
  //watchdog_counter++;
  long_watchdog_counter++;
  short_watchdog_counter++;
}

// 0=16ms, 1=32ms, 2=64ms, 3=128ms, 4=250ms, 5=500ms
// 6=1sec, 7=2sec, 8=4sec, 9=8sec
// From: http://interface.khm.de/index.php/lab/experiments/sleep_watchdog_battery/
void setup_watchdog(int timerPrescaler) {

  if (timerPrescaler > 9 ) timerPrescaler = 9; //Correct incoming amount if need be

  byte bb = timerPrescaler & 7; 
  if (timerPrescaler > 7) bb |= (1<<5); //Set the special 5th bit if necessary

  //This order of commands is important and cannot be combined
  MCUSR &= ~(1<<WDRF); //Clear the watch dog reset
  WDTCSR |= (1<<WDCE) | (1<<WDE); //Set WD_change enable, set WD enable
  WDTCSR = bb; //Set new watchdog timeout value
  WDTCSR |= _BV(WDIE); //Set the interrupt enable, this will keep unit from resetting after each int
}


/* Global Objects */
//Atmega328p on a Arduino nano platform is used here.

//Carbon-monoxyde sensor. Pin config: PWM is on pin D5, Pin A2 is for reading
//MQ7 MQ7_Sensor(5,2);
//Ozone sensor. Pin config: Vo is on pin A0.
O3_spec_sensor O3_spec_sensor(0); 
//Dust sensor.  Pin config: Pin D4.
sharp_dust_sensor sharp_dust_sensor(4);
//GPS. Pin config: blue wire (TX) on D8 , green wire (RX) on D9.
GPS gps_sensor(8,9);
//Luminosity sensor. Pin config: (I2C protocol) SDA to A4, SCL to A5
//LUX lux_sensor;
//Soil moisture sensor. Pin config : Pin A1.
soil_moisture soil_moisture(1);
//Soil temperature sensor. Pin config :  Pin D3.
DFR0198 DFR0198(3);
//DHT11 sensor for temperature + humidity. Using pin D2.
//dht11 dht11(2);
//DHT22 sensor for temperature + humidity. Using pin D2.
dht22 dht22(2);


//Two Main function to scan sensor/send with LoRa module.
//long_sensor_node_execute sends O3,Dust,GPS. 
//  Takes more then 40sec to execute because of GPS wakeup time. 
void long_sensor_node_execute(void);
//short_sensor_node_execute sends soil humidity, soil temperature, air humidity, air temperature, battery life.
void short_sensor_node_execute(void);

void setup()
{
  //Solar pannel control mosfet on D7, NOT USED.
  pinMode(7, OUTPUT);
  digitalWrite(7, 0);
}

void loop(void)
{
  //Scanning of O3, Dust, GPS.
  if((long_watchdog_counter > ONE_HOUR_TIMEOUT)){

    sleep_disable(); 
    ADCSRA |= (1<<ADEN); //Enable ADC

    //long_watchdog_counter = 0;

    //Serial.print("Got in at : ");Serial.println(long_watchdog_counter);
    //EnableSensor Pin
    //Active les lignes 3V,3.3V,5V pour les sensors
    pinMode(6, OUTPUT);
    digitalWrite(6, 1);

    //Execute le sensor node pour le O3, Dust, GPS.
    //GPS needs time to be ready for aquiring.
    //It's about 40 secs in my room.
    long_sensor_node_execute();

    //Desactive les lignes 3V,3.3V,5V pour les sensors
    digitalWrite(6, 0);

    //Reset long_watchdog_counter
    long_watchdog_counter = 0;
  }

  //Scanning Soil humidity, soil temperature, air humidity, air temperature, battery voltage.
  if((short_watchdog_counter > TEN_MINUTES_TIMEOUT)){

    sleep_disable(); 
    ADCSRA |= (1<<ADEN); //Enable ADC

    //EnableSensor Pin
    //Active les lignes 3V,3.3V,5V pour les sensors
    pinMode(6, OUTPUT);
    digitalWrite(6, 1);

    //Execute le sensor node. This one is fast
    short_sensor_node_execute();

    //Desactive les lignes 3V,3.3V,5V pour les sensors
    digitalWrite(6, 0);

    //Reset short_watchdog_counter
    short_watchdog_counter = 0;
  }

  setup_watchdog(6); //Setup watchdog to go off after 1sec
  set_sleep_mode(SLEEP_MODE_PWR_DOWN); //Power down everything, wake up from WDT
  sleep_enable();
  ADCSRA &= ~(1<<ADEN); //Disable ADC, saves ~230uA
  sleep_mode();//Sleeps now! Wow, current is now 0.27mA!
  //sleep_disable(); 
  //ADCSRA |= (1<<ADEN); //Enable ADC
     
}

void long_sensor_node_execute(void){

  //GPS needs time to wake up.
  //It's about 40 secs in my room.
  delay(40000);

  //Lora module init, also inits Serial at 38400 Baud.
  Lora_init();

  /* Sensor scanning begins */

  //O3 sensor.
  O3_spec_sensor.scan();
  delay(1000);

  //Dust sensor
  sharp_dust_sensor.scan();
  delay(1000);

  //GPS
  gps_sensor.scan();
  delay(1000);

  /* Sensor done scanning */

  /* Preparing LoRa transmission */
  int O3_concentration = (int)O3_spec_sensor.get_concentration(); //in ppb.
  int dust_concentration = (int)sharp_dust_sensor.get_concentration(); //in micro gram per cubic meter.
  //There is a significative association. Currently dust sensor kills program if does not anwser back.
  //int dust_concentration = 46+O3_concentration;
  float lat = gps_sensor.get_lat();
  float lon = gps_sensor.get_lon();

  //LoRA Communication
  // A -> O3 concentration
  // B -> Dust concentration
  // CI -> GPS (lat)
  // CII -> GPS (lon)
  // D -> Lux
  // E -> Soil humidity
  // F -> Soil temperature
  // G -> Air humidity
  // H -> Air temperature
  // I -> Battery life (in % left)

  // Trame
  // "\\!node1:A=%d:B=%d:C=%d:D=%d:E=%d:F=%d:G=%d:H=%d"

  //Required for Float representation since %f in sprintf is not supported in Arduino.
  //Example
  // static float f_val = 123.6794;
  // static char outstr[15];
  // dtostrf(f_val,7, 3, outstr);
  // The output of this is 123.679

  //lat to string. Lat can be -90.000000 to 90.000000
  char lat_string[15];
  dtostrf(lat,10, 6, lat_string);

  //lon to string. Lon can be -180.000000 to 180.000000
  char lon_string[15];
  dtostrf(lon,11, 6, lon_string);

  //String to send.
  char string[75] = {0};
 
  // //The one to send for all sensors
  // sprintf(string, "\\!node1:A=%d:B=%d:C=%s,%s:D=%d:E=%d:F=%d:G=%d:H=%d", 
  //                   O3_concentration,dust_concentration, lat_string, lon_string, 
  //                    lux, soil_humidity, soil_temperature, air_humidity, air_temperature);

  //The one to send O3, Dust, GPS
  sprintf(string, "\\!node1:A=%d:B=%d:CI=%s:CII=%s", 
                    O3_concentration,dust_concentration, lat_string, lon_string);

  //Strangely, this those not work...
  // sprintf(string, "\\!node1:A=%d:B=%d:C1=%s:C2=%s", 
  //                   O3_concentration,dust_concentration, lat_string, lon_string);

  // sprintf(string, "\\!node1:A=%d:B=%d:C=%s,%s", 
  //                   O3_concentration,dust_concentration, lat_string, lon_string);

  Lora_send_string(string);

  delay(1000);

  //Take out MOSI and CS on LoRaModule. Put them to ground.
  digitalWrite(11, 0);//pin D11 is MOSI
  digitalWrite(10, 0);//pin D10 is MOSI

  //End serial communication
  Serial.end();

}

void short_sensor_node_execute(void){

  //Lora module init, also inits Serial at 38400 Baud.
  Lora_init();

  /* Sensor scanning begins */

  // //Luminosity sensor  -> No more room in Atmega328P.
  //lux_sensor.scan();
  //delay(1000);

  //Soil moisture
  soil_moisture.scan();
  delay(2000);

  //Soil temperature
  DFR0198.scan();
  delay(2000);

  //Scan temperature and humidity
  dht22.scan();
  delay(2000);

  /* Sensor done scanning */

  /* Preparing LoRa transmission */

  //unsigned int lux = lux_sensor.get_lux();
  unsigned int lux = 0;

  //Off by 10% RH, calibrated with DHT22.
  int soil_humidity = soil_moisture.get_moisture()+10;
  

  // float soil_temperature = DFR0198.get_temperature();
  // //need to convert float to string
  // char soil_temperature_string[15];
  // dtostrf(soil_temperature,7, 1, soil_temperature_string);

  //int air_humidity = dht11.get_humidity();
  //int air_temperature = dht11.get_temperature();
  float air_humidity = dht22.get_humidity();
  float air_temperature = dht22.get_temperature();

  char air_humidity_string[15] = {0};
  dtostrf(air_humidity,5, 1, air_humidity_string);

  char air_temperature_string[15] = {0};
  dtostrf(air_temperature,5, 1, air_temperature_string);

  float soil_temperature = DFR0198.get_temperature();
  //get ride of weird error on first reading.
  if(soil_temperature>80){
    soil_temperature = air_temperature-2.0;
  }
  //need to convert float to string
  char soil_temperature_string[15];
  dtostrf(soil_temperature,7, 1, soil_temperature_string);

  //int battery_life = 99; Battery voltage on PIN A3.
  //analogRead outputs a value from 0-1023 depending on Voltage.
  //Battery max voltage is 3.7V, 2600mAh. Value is divided by 2 with a voltage divider.
  float battery_life = (((float)analogRead(3))*5.0/1024.0)*2.0;
  //Adjusting, reading was 3.88 and supposed to be 3.70
  battery_life = (battery_life - 0.16)*0.97;
  char battery_life_string[15] = {0};
  dtostrf(battery_life,7, 2, battery_life_string);

  //LoRA Communication
  // A -> O3 concentration
  // B -> Dust concentration
  // CI -> GPS (lat)
  // CII -> GPS (lon)
  // D -> Lux
  // E -> Soil humidity
  // F -> Soil temperature
  // G -> Air humidity
  // H -> Air temperature
  // I -> Battery life (in % left)

  // Trame
  // "\\!node1:A=%d:B=%d:C=%d:D=%d:E=%d:F=%d:G=%d:H=%d:I=%d"

  //String to send
  //char string[75] = {0};
  char string[150] = {0};
  // sprintf(string, "\\!node1:temperature_air=%d:humidity_air=%d", air_temperature,air_humidity);
 
  //The one to send for all sensors
  // sprintf(string, "\\!node1:D=%d:E=%d:F=%d:G=%d:H=%d:I=%d", 
  //                   lux, soil_humidity, soil_temperature, air_humidity, air_temperature,battery_life);
  // sprintf(string, "\\!node1:D=%d:E=%d:F=%s:G=%d:H=%d:I=%d", 
  //                   lux, soil_humidity, soil_temperature_string, air_humidity, air_temperature,battery_life);
  // sprintf(string, "\\!node1:D=%d:E=%d:F=%s:G=%s:H=%s:I=%d", 
  //                   lux, soil_humidity, soil_temperature_string, air_humidity_string, air_temperature_string,battery_life);
  sprintf(string, "\\!node1:D=%d:E=%d:F=%s:G=%s:H=%s:I=%s", 
                    lux, soil_humidity, soil_temperature_string, air_humidity_string, air_temperature_string,battery_life_string);

  Lora_send_string(string);

  delay(1000);

  //Take out MOSI and CS on LoRaModule. Put them to ground.
  digitalWrite(11, 0);//pin D11 is MOSI
  digitalWrite(10, 0);//pin D10 is MOSI

  //End serial communication
  Serial.end();

}

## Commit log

2017-09-23 POWER: track files rather than archive
    [Alim_pinout.ods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]
2017-09-23 SENSOR_UNIT: track files rather than archive
    [Noeud-B.Cu.gbr, Noeud-B.SilkS.gbr, Noeud-Cmts.User.gbr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]
2017-09-23 POWER: untrack archive within the archive
    Same as previous
2017-09-23 POWER: Unwrap one layer of directory
    [Alim_pinout.ods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]
2017-09-23 SENSOR_UNIT: unwrap one layer of directory
    [Noeud-B.Cu.gbr, Noeud-B.SilkS.gbr, Noeud-Cmts.User.gbr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]
